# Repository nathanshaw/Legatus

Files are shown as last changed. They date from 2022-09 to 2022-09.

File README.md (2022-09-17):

# Legatus Hardware

This repo contains the PCB layout and schematic files for the Legatus genus.
Legatus is one of three genera developed for the Acropolis family of soundscape augmentation artefacts. Legatus specialises in loudspeaker-based cochlear soundscape augmentation.

The files were created within EAGLE CAD

The Legatus genus firmware is contained in this repo: https://github.com/nathanshaw/unified_hss_firmware

More information about this project can be found here: https://nathanvillicanashaw.com/archive
The Explorator genus can be found here: https://github.com/nathanshaw/explorator
The Speculator genus can be found here: https://github.com/nathanshaw/speculator

The following PCB design is included in this repo:
----------------------------------------------------

### Legatus major
    86mm diameter
    1x Teensy 3.2 Microcontroller
    1x power switch
    6x firmware control switches
    2x firmware control potentiometers
    10x WS2813 NeoPixel LEDs
    2x VEML 6030 Ambient Light Sensors
    1x 5v voltage regulator (D24V50F5): https://www.pololu.com/product/2851
    1x SHTC3 Temperature and Humidity Sensor
    2x onboard 18500 LiPo Batteries
    1x button controller IC
    1x audio amplifier breakout PCB
    1x SGTL5000 Breakout PCB
    2x TDK ICS-43434 MEMs microphone

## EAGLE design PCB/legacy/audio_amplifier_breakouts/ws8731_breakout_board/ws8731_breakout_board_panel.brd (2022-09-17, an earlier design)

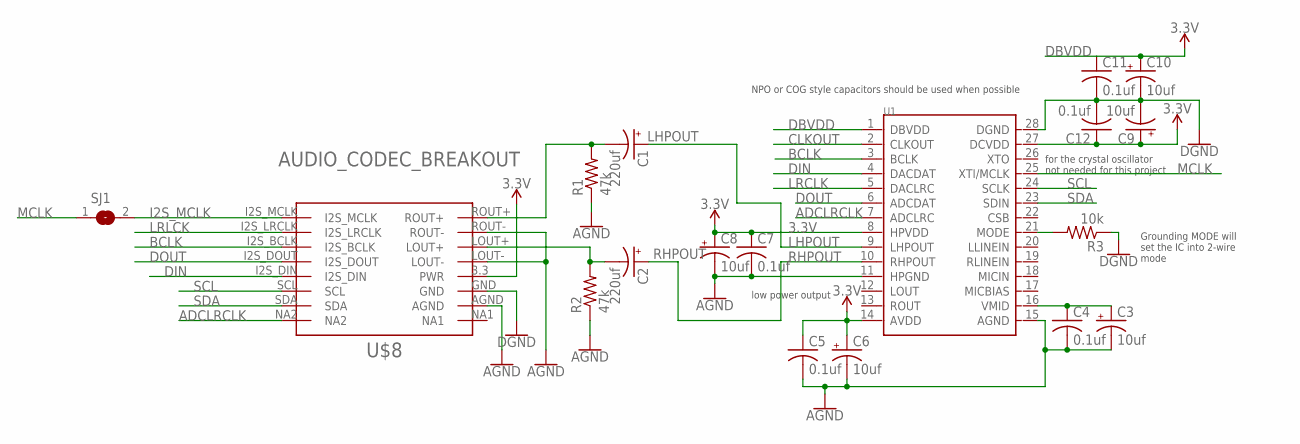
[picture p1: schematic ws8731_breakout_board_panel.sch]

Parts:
C1, C2: 220uf; PANASONIC_D
C3, C6, C8, C9, C10: 10uf; 153CLV-0505
C4, C5, C7, C11, C12: 0.1uf; C0805K
R1, R2: 47k; R0805
R3: 10k; R0805
SJ1: SJ
U1: CODECODER-WM8731SEDS/V(SSOP28); SSOP28-0.65-10.2X5.2MM
U$8: AUDIO_CODEC_BREAKOUT; HSS_CODEC_BREAKOUT

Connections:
3.3V: C5.1, C6.+, C7.1, C8.+, C9.+, C12.1, U1.8 (HPVDD), U1.14 (AVDD), U1.27 (DCVDD), U$8.3.3 (PWR)
ADCLRCLK: U1.7 (ADCLRC), U$8.NA2
AGND: C3.-, C4.2, C5.2, C6.-, C7.2, C8.-, R1.1, R2.1, U1.11 (HPGND), U1.15 (AGND), U$8.AGND, U$8.LOUT-, U$8.ROUT-
BCLK: U1.3 (BCLK), U$8.I2S_BCLK
CLKOUT: U1.2 (CLKOUT)
DBVDD: C10.+, C11.1, U1.1 (DBVDD)
DGND: C9.-, C10.-, C11.2, C12.2, R3.1, U1.28 (DGND)
DIN: U1.4 (DACDAT), U$8.I2S_DIN
DOUT: U1.6 (ADCDAT), U$8.I2S_DOUT
GND: U$8.GND
I2S_MCLK: SJ1.2, U$8.I2S_MCLK
LHPOUT: C1.+, U1.9 (LHPOUT)
LRCLK: U1.5 (DACLRC)
LRLCK: U$8.I2S_LRCLK
MCLK: SJ1.1, U1.25 (XTI/MCLK)
MODE: R3.2, U1.21 (MODE)
unnamed: C1.-, R1.2, U$8.ROUT+
unnamed: C2.-, R2.2, U$8.LOUT+
unnamed: C3.+, C4.1, U1.16 (VMID)
RHPOUT: C2.+, U1.10 (RHPOUT)
SCL: U1.24 (SCLK), U$8.SCL
SDA: U1.23 (SDIN), U$8.SDA

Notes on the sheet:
low power output
NPO or COG style capacitors should be used when possible
Grounding MODE will set the IC into 2-wire mode
for the crystal oscillator not needed for this project

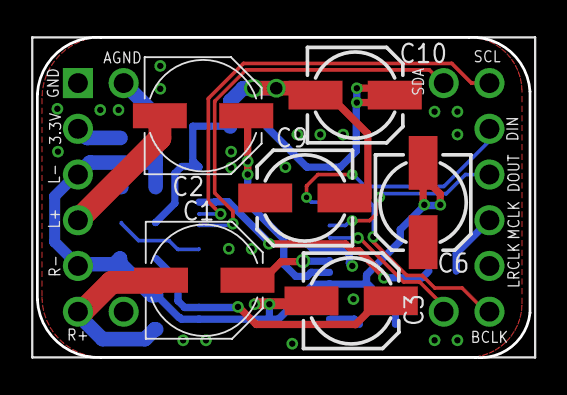
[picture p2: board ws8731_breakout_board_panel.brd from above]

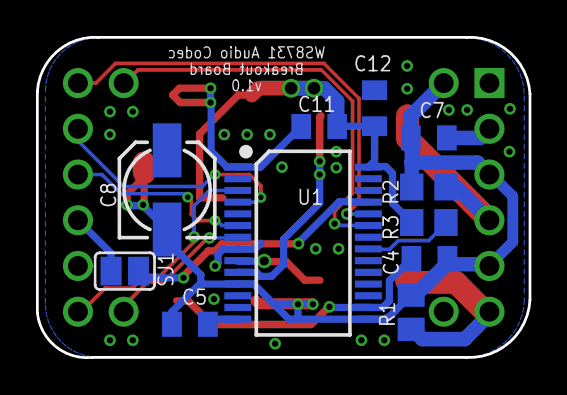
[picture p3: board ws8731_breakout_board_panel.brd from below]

Board: 2 copper layers, 27.4 x 17.8 mm, 18 parts (11 on the bottom side), 18 nets.

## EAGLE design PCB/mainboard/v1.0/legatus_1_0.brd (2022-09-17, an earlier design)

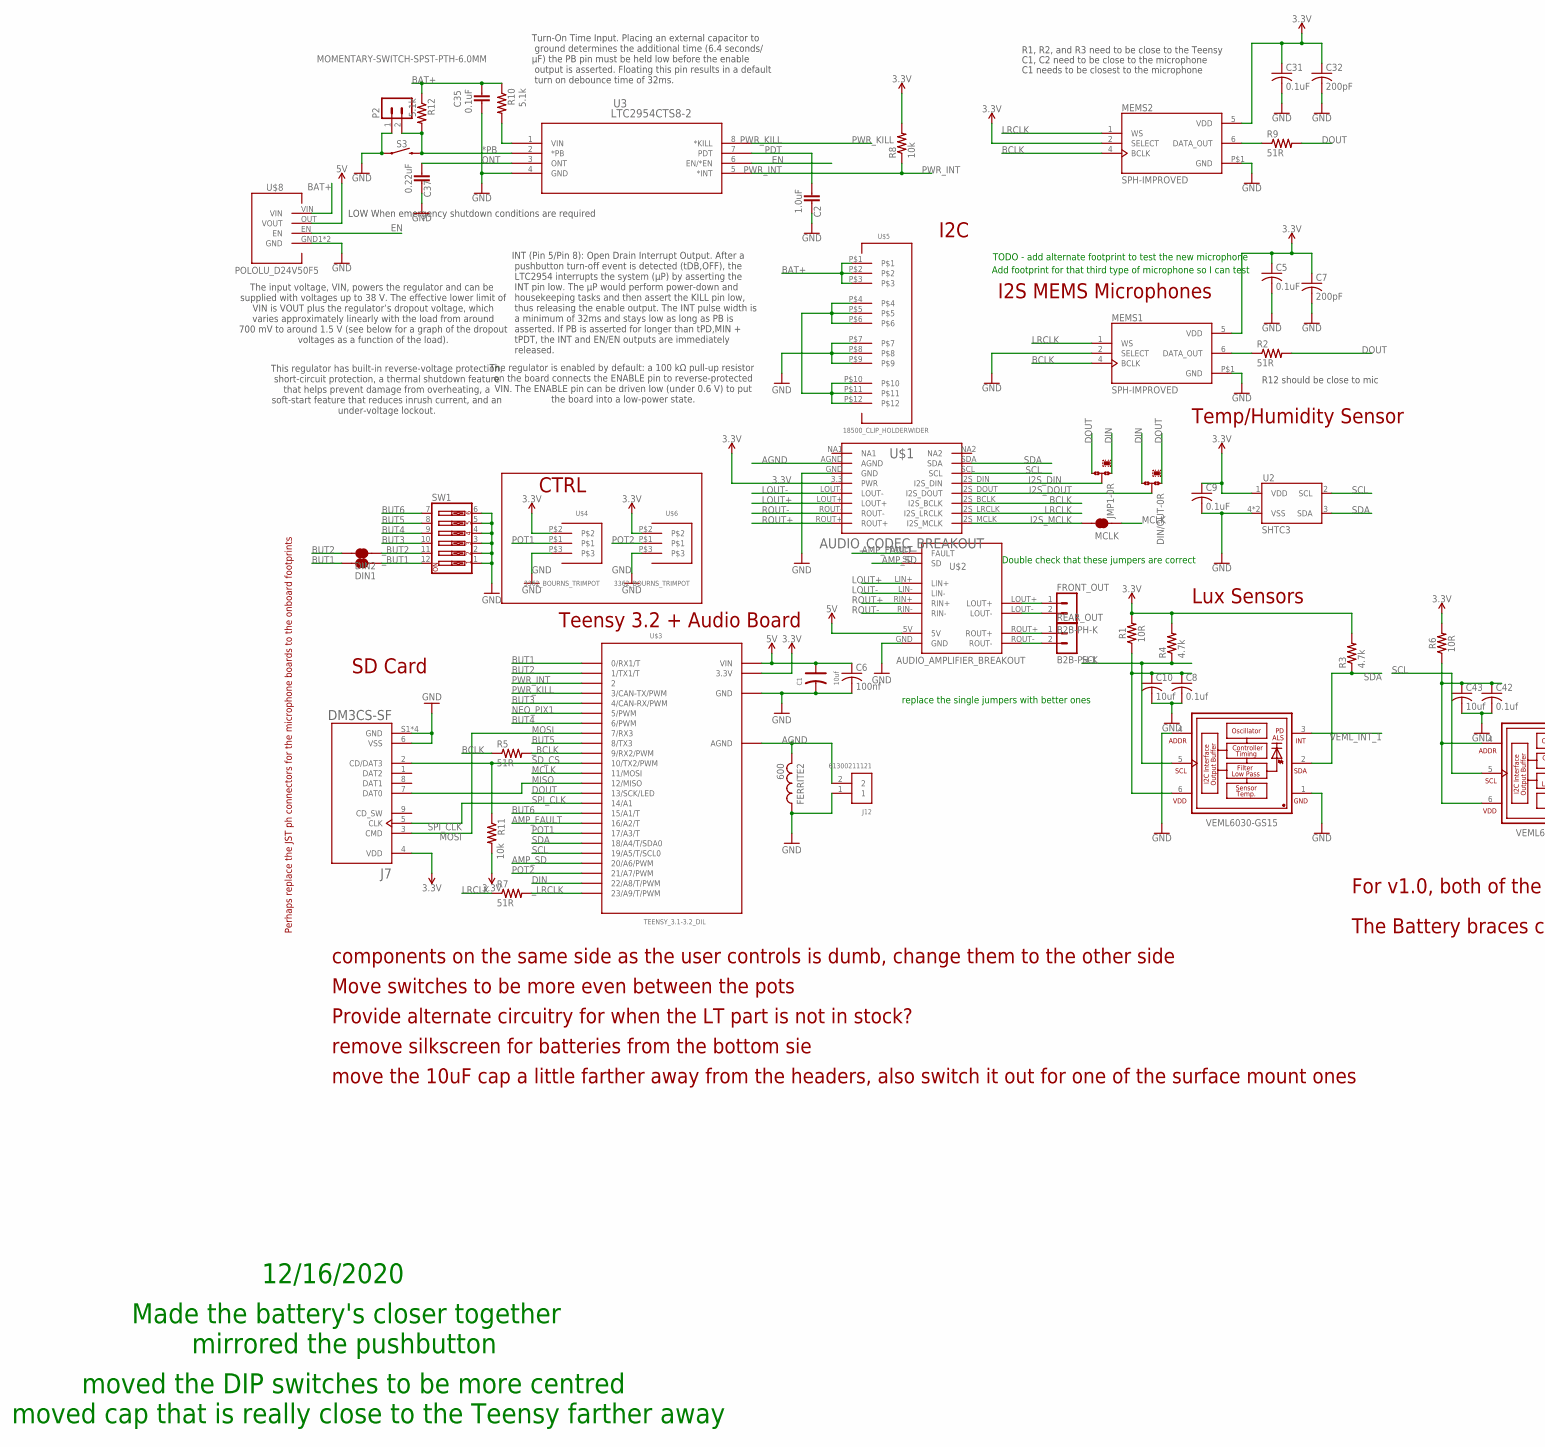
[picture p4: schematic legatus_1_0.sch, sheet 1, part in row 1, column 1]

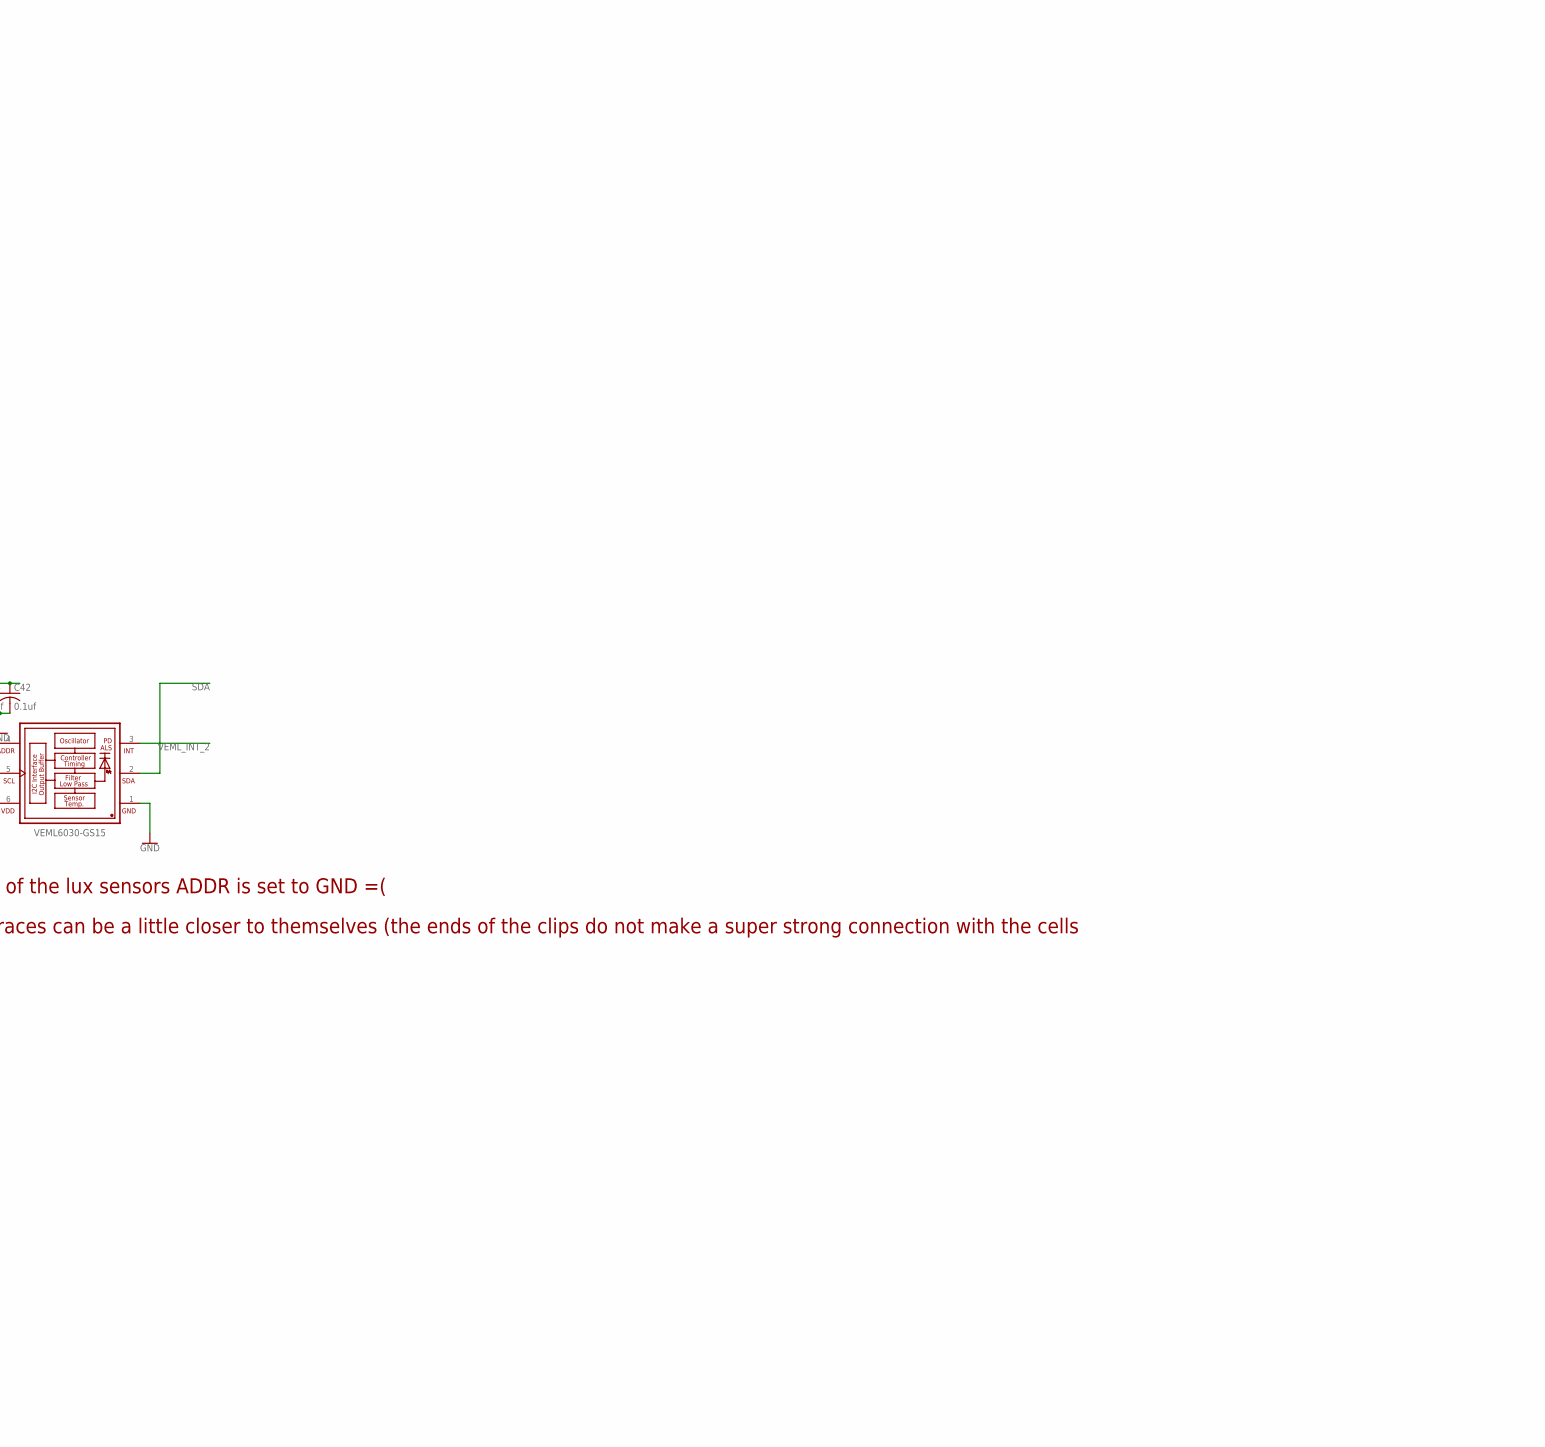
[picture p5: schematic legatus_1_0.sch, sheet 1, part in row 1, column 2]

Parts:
C1: 10uf; PC-D5.3MM
C2: 1.0uF; CAPC2012X110
C5, C9, C31: 0.1uF; C0805
C6: 100nf; C2012
C7, C32: 200pF; C0805
C8, C42: 0.1uf; C0805
C10, C43: 10uf; C0805
C35: 0.1uF; CAPC2012X110
C37: 0.22uF; CAPC2012X110
DIN1, DIN2: JUMPER-SMT_2_NC_TRACE_SILK; SMT-JUMPER_2_NC_TRACE_SILK
DIN/OUT: 0R-JUMPB; B0R-JMP
FERRITE2: 600; RESC0805_N
FRONT_OUT: B2B-PH-K
J7: DM3CS-SF; HRS_DM3CS-SF
J12: 61300211121
JMP1: 0R-JUMPB; B0R-JMP
MCLK: JUMPER-SMT_2_NC_TRACE_SILK; SMT-JUMPER_2_NC_TRACE_SILK
MEMS1, MEMS2: SPH-IMPROVED; MIC_SPH0645LM4H-B_LARGER_RING
P2: B2B-PH-K
R1, R6: 10R; R0805
R2, R5, R7, R9: 51R; M0805
R3, R4: 4.7k; M0805
R8: 10k; R0805
R10, R12: 5.1k; R0805
R11: 10k; M0805
REAR_OUT: B2B-PH-K
S3: MOMENTARY-SWITCH-SPST-PTH-6.0MM; TACTILE_SWITCH_PTH_6.0MM
SW1: SW_DIP-6; EDG-06
U2: SHTC3
U3: LTC2954CTS8-2; TSOT-23_TS8
U$1: AUDIO_CODEC_BREAKOUT; HSS_CODEC_BREAKOUT
U$2: AUDIO_AMPLIFIER_BREAKOUT
U$3: TEENSY_3.1-3.2_DIL; TEENSY_3.0-3.2&LC_DIL
U$4, U$6: 3362_BOURNS_TRIMPOT
U$5: 18500_CLIP_HOLDERWIDER; 3PINBATTERY_CLIP_WIDER
U$8: POLOLU_D24V50F5
VMEL1, VMEL2: VEML6030-GS15; VISHAY_VEML6030_2X2X0.87

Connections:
3.3V: C5.1, C7.1, C9.1, C31.1, C32.1, J7.4 (VDD), MEMS1.5 (VDD), MEMS2.2 (SELECT), MEMS2.5 (VDD), R1.2, R3.2, R4.2, R6.2, R8.2, R11.2, U2.1 (VDD), U$1.3.3 (PWR), U$3.3.3V, U$4.P$2, U$6.P$2
5V: C1.+, C6.1, U$2.5V, U$3.VIN, U$8.OUT (VOUT); also elsewhere on the board
*PB: P2.2, R12.2, S3.3 (2), U3.2 (*PB)
AGND: FERRITE2.2, J12.2, U$1.AGND, U$3.AGND
AMP_FAULT: U$2.FAULT, U$3.16/A2 (16/A2/T)
AMP_SD: U$2.SD, U$3.20/A6 (20/A6/PWM)
BAT+: C35.1, R10.1, R12.1, U$5.P$1, U$5.P$2, U$5.P$3, U$8.VIN
BCLK: MEMS1.4 (BCLK), MEMS2.4 (BCLK), R5.1, U$1.I2S_BCLK
BUT1: DIN1.1, U$3.0 (0/RX1/T)
BUT2: DIN2.1, U$3.1 (1/TX1/T)
BUT3: SW1.10, U$3.4 (4/CAN-RX/PWM)
BUT4: SW1.9, U$3.6 (6/PWM)
BUT5: SW1.8, U$3.8 (8/TX3)
BUT6: SW1.7, U$3.15/A1 (15/A1/T)
DIN: DIN/OUT.3, JMP1.1, U$3.22/A8 (22/A8/T/PWM)
DOUT: DIN/OUT.1, JMP1.3, R2.2, R9.2, U$3.13 (13/SCK/LED)
EN: U3.6 (EN/*EN), U$8.EN
GND: C1.-, C2.2, C5.2, C6.2, C7.2, C8.2, C9.2, C10.2, C31.2, C32.2, C35.2, C37.2, C42.2, C43.2, FERRITE2.1, J7.6 (VSS), J7.S1 (GND), J7.S2 (GND), J7.S3 (GND), J7.S5 (GND), J12.1, MEMS1.2 (SELECT), MEMS1.P$1 (GND), MEMS2.P$1 (GND), P2.1, S3.1, SW1.1, SW1.2, SW1.3, SW1.4, SW1.5, SW1.6, U2.4 (VSS), U2.5 (VSS), U3.4 (GND), U$1.GND, U$2.GND, U$3.GND, U$4.P$3, U$5.P$7, U$5.P$8, U$5.P$9, U$6.P$3, U$8.GND1 (GND), U$8.GND2 (GND), VMEL1.1 (GND), VMEL1.4 (ADDR), VMEL2.1 (GND); also elsewhere on the board
I2S_DIN: JMP1.2, U$1.I2S_DIN
I2S_DOUT: DIN/OUT.2, U$1.I2S_DOUT
I2S_MCLK: MCLK.1, U$1.I2S_MCLK
LOUT+: U$1.LOUT+, U$2.LIN+
LOUT-: U$1.LOUT-, U$2.LIN-
LRCLK: MEMS1.1 (WS), MEMS2.1 (WS), R7.1, U$1.I2S_LRCLK
MCLK: MCLK.2, U$3.11 (11/MOSI)
MISO: J7.7 (DAT0), U$3.12 (12/MISO)
MOSI: J7.3 (CMD), U$3.7 (7/RX3)
unnamed: MEMS1.6 (DATA_OUT), R2.1
unnamed: U$5.P$4, U$5.P$5, U$5.P$6, U$5.P$10, U$5.P$11, U$5.P$12
unnamed: C42.1, C43.1, R6.1, VMEL2.4 (ADDR), VMEL2.6 (VDD)
unnamed: C8.1, C10.1, R1.1, VMEL1.6 (VDD)
unnamed: R10.2, U3.1 (VIN)
unnamed: MEMS2.6 (DATA_OUT), R9.1
unnamed: REAR_OUT.2, U$2.ROUT-
unnamed: REAR_OUT.1, U$2.ROUT+
unnamed: FRONT_OUT.2, U$2.LOUT-
unnamed: FRONT_OUT.1, U$2.LOUT+
NEO_PIX1: U$3.5 (5/PWM); also elsewhere on the board
ONT: C37.1, U3.3 (ONT)
PDT: C2.1, U3.7 (PDT)
POT1: U$3.17/A3 (17/A3/T), U$4.P$1
POT2: U$3.21/A7 (21/A7/PWM), U$6.P$1
PWR_INT: R8.1, U3.5 (*INT), U$3.2
PWR_KILL: U3.8 (*KILL), U$3.3 (3/CAN-TX/PWM)
ROUT+: U$1.ROUT+, U$2.RIN+
ROUT-: U$1.ROUT-, U$2.RIN-
SCL: R4.1, U2.2 (SCL), U$1.SCL, U$3.19/A5 (19/A5/T/SCL0), VMEL1.5 (SCL), VMEL2.5 (SCL)
SDA: R3.1, U2.3 (SDA), U$1.SDA, U$3.18/A4 (18/A4/T/SDA0), VMEL1.2 (SDA), VMEL2.2 (SDA)
SD_CS: J7.2 (CD/DAT3), R11.1, U$3.10 (10/TX2/PWM)
SPI_CLK: J7.5 (CLK), U$3.14/A0 (14/A1)
VEML_INT_1: VMEL1.3 (INT)
VEML_INT_2: VMEL2.3 (INT)
_BCLK: R5.2, U$3.9 (9/RX2/PWM)
_BUT1: DIN1.2, SW1.12
_BUT2: DIN2.2, SW1.11
_LRCLK: R7.2, U$3.23/A9 (23/A9/T/PWM)

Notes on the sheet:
I2C
Teensy 3.2 + Audio Board
CTRL
Perhaps replace the JST ph connectors for the microphone boards to the onboard footprints
I2S MEMS Microphones
R12 should be close to mic
Temp/Humidity Sensor
10R
Lux Sensors
SD Card
Add footprint for that third type of microphone so I can test
R1, R2, and R3 need to be close to the Teensy
C1, C2 need to be close to the microphone
C1 needs to be closest to the microphone
This regulator has built-in reverse-voltage protection, short-circuit protection, a thermal shutdown feature that helps prevent damage from overheating, a soft-start feature that reduces inrush current, and an under-voltage lockout.
The input voltage, VIN, powers the regulator and can be supplied with voltages up to 38 V. The effective lower limit of VIN is VOUT plus the regulator’s dropout voltage, which varies approximately linearly with the load from around 700 mV to around 1.5 V (see below for a graph of the dropout voltag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
The regulator is enabled by default: a 100 kΩ pull-up resistor on the board connects the ENABLE pin to reverse-protected VIN. The ENABLE pin can be driven low (under 0.6 V) to put the board into a low-power state.
LOW When emergency shutdown conditions are required
Turn-On Time Input. Placing an external capacitor to ground determines the additional time (6.4 seconds/ μF) the PB pin must be held low before the enable output is asserted. Floating this pin results in a default turn on debounce time of 32ms.
INT (Pin 5/Pin 8): Open Drain Interrupt Output. After a pushbutton turn-off event is detected (tDB,OFF), the LTC2954 interrupts the system (μP) by asserting the INT pin low. The μP would perform power-down and housekeeping tasks and then assert the KILL pin low, thus releasing the enable output. Th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
TODO - add alternate footprint to test the new microphone
Double check that these jumpers are correct
replace the single jumpers with better ones
components on the same side as the user controls is dumb, change them to the other side
Move switches to be more even between the pots
remove silkscreen for batteries from the bottom sie
move the 10uF cap a little farther away from the headers, also switch it out for one of the surface mount ones
Provide alternate circuitry for when the LT part is not in stock?
For v1.0, both of the lux sensors ADDR is set to GND =(
The Battery braces can be a little closer to themselves (the ends of the clips do not make a super strong connection with the cells
Made the battery's closer together
12/16/2020
mirrored the pushbutton
moved the DIP switches to be more centred
moved cap that is really close to the Teensy farther away

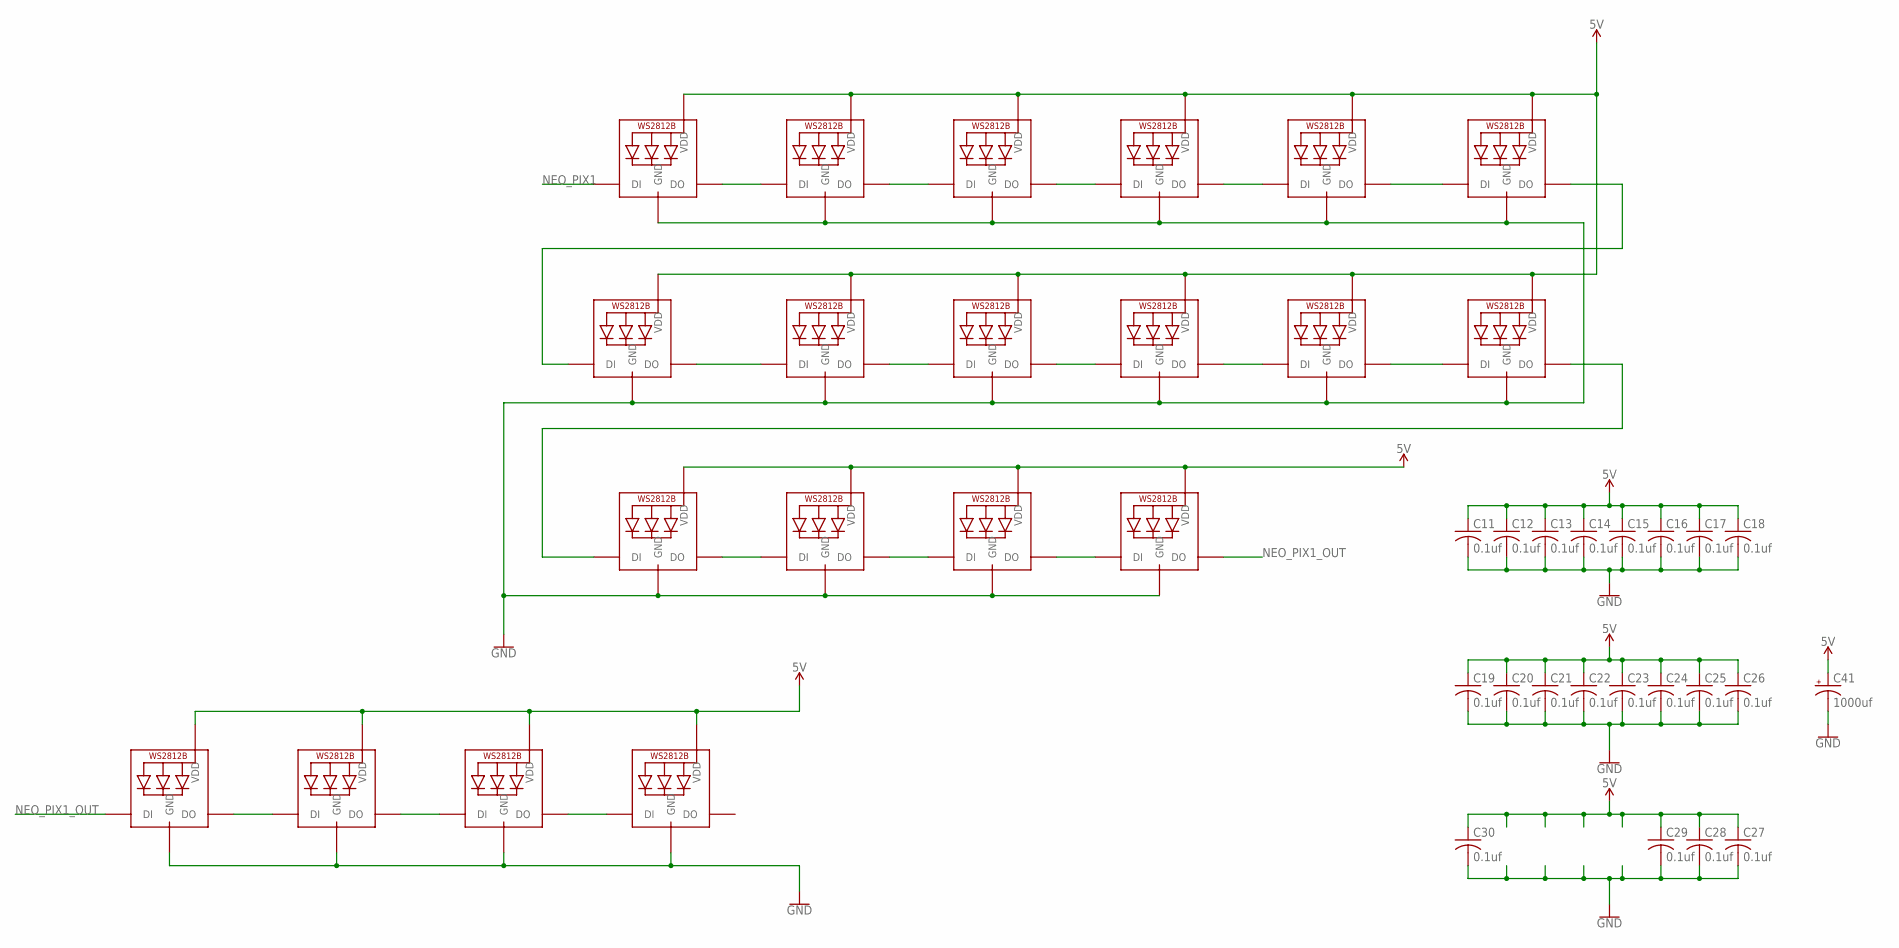
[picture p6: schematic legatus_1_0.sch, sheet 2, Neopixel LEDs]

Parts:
C11, C12, C13, C14, C15, C16, C17, C18, C19, C20, C21, C22, C23, C24, C25, C26, C27, C28, C29, C30: 0.1uf; C0805
C41: 1000uf; 153CLV-1010
LED1, LED2, LED3, LED4, LED5, LED6, LED7, LED8, LED9, LED10, LED11, LED12, LED13, LED14, LED15, LED16, LED17, LED18, LED19, LED20: WS2812B_5050N; WS2812B-NARROW

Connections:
5V: C11.1, C12.1, C13.1, C14.1, C15.1, C16.1, C17.1, C18.1, C19.1, C20.1, C21.1, C22.1, C23.1, C24.1, C25.1, C26.1, C27.1, C28.1, C29.1, C30.1, C41.+, LED1.1-VDD (VDD), LED2.1-VDD (VDD), LED3.1-VDD (VDD), LED4.1-VDD (VDD), LED5.1-VDD (VDD), LED6.1-VDD (VDD), LED7.1-VDD (VDD), LED8.1-VDD (VDD), LED9.1-VDD (VDD), LED10.1-VDD (VDD), LED11.1-VDD (VDD), LED12.1-VDD (VDD), LED13.1-VDD (VDD), LED14.1-VDD (VDD), LED15.1-VDD (VDD), LED16.1-VDD (VDD), LED17.1-VDD (VDD), LED18.1-VDD (VDD), LED19.1-VDD (VDD), LED20.1-VDD (VDD); also elsewhere on the board
GND: C11.2, C12.2, C13.2, C14.2, C15.2, C16.2, C17.2, C18.2, C19.2, C20.2, C21.2, C22.2, C23.2, C24.2, C25.2, C26.2, C27.2, C28.2, C29.2, C30.2, C41.-, LED1.3-GND (GND), LED2.3-GND (GND), LED3.3-GND (GND), LED4.3-GND (GND), LED5.3-GND (GND), LED6.3-GND (GND), LED7.3-GND (GND), LED8.3-GND (GND), LED9.3-GND (GND), LED10.3-GND (GND), LED11.3-GND (GND), LED12.3-GND (GND), LED13.3-GND (GND), LED14.3-GND (GND), LED15.3-GND (GND), LED16.3-GND (GND), LED17.3-GND (GND), LED18.3-GND (GND), LED19.3-GND (GND), LED20.3-GND (GND); also elsewhere on the board
unnamed: LED1.2-DOUT (DO), LED2.4-DIN (DI)
unnamed: LED2.2-DOUT (DO), LED3.4-DIN (DI)
unnamed: LED3.2-DOUT (DO), LED4.4-DIN (DI)
unnamed: LED4.2-DOUT (DO), LED5.4-DIN (DI)
unnamed: LED5.2-DOUT (DO), LED6.4-DIN (DI)
unnamed: LED7.2-DOUT (DO), LED8.4-DIN (DI)
unnamed: LED8.2-DOUT (DO), LED9.4-DIN (DI)
unnamed: LED9.2-DOUT (DO), LED10.4-DIN (DI)
unnamed: LED10.2-DOUT (DO), LED11.4-DIN (DI)
unnamed: LED11.2-DOUT (DO), LED12.4-DIN (DI)
unnamed: LED13.2-DOUT (DO), LED14.4-DIN (DI)
unnamed: LED14.2-DOUT (DO), LED15.4-DIN (DI)
unnamed: LED15.2-DOUT (DO), LED16.4-DIN (DI)
unnamed: LED12.2-DOUT (DO), LED13.4-DIN (DI)
unnamed: LED6.2-DOUT (DO), LED7.4-DIN (DI)
unnamed: LED18.2-DOUT (DO), LED19.4-DIN (DI)
unnamed: LED19.2-DOUT (DO), LED20.4-DIN (DI)
unnamed: LED17.2-DOUT (DO), LED18.4-DIN (DI)
NEO_PIX1: LED1.4-DIN (DI); also elsewhere on the board
NEO_PIX1_OUT: LED16.2-DOUT (DO), LED17.4-DIN (DI)

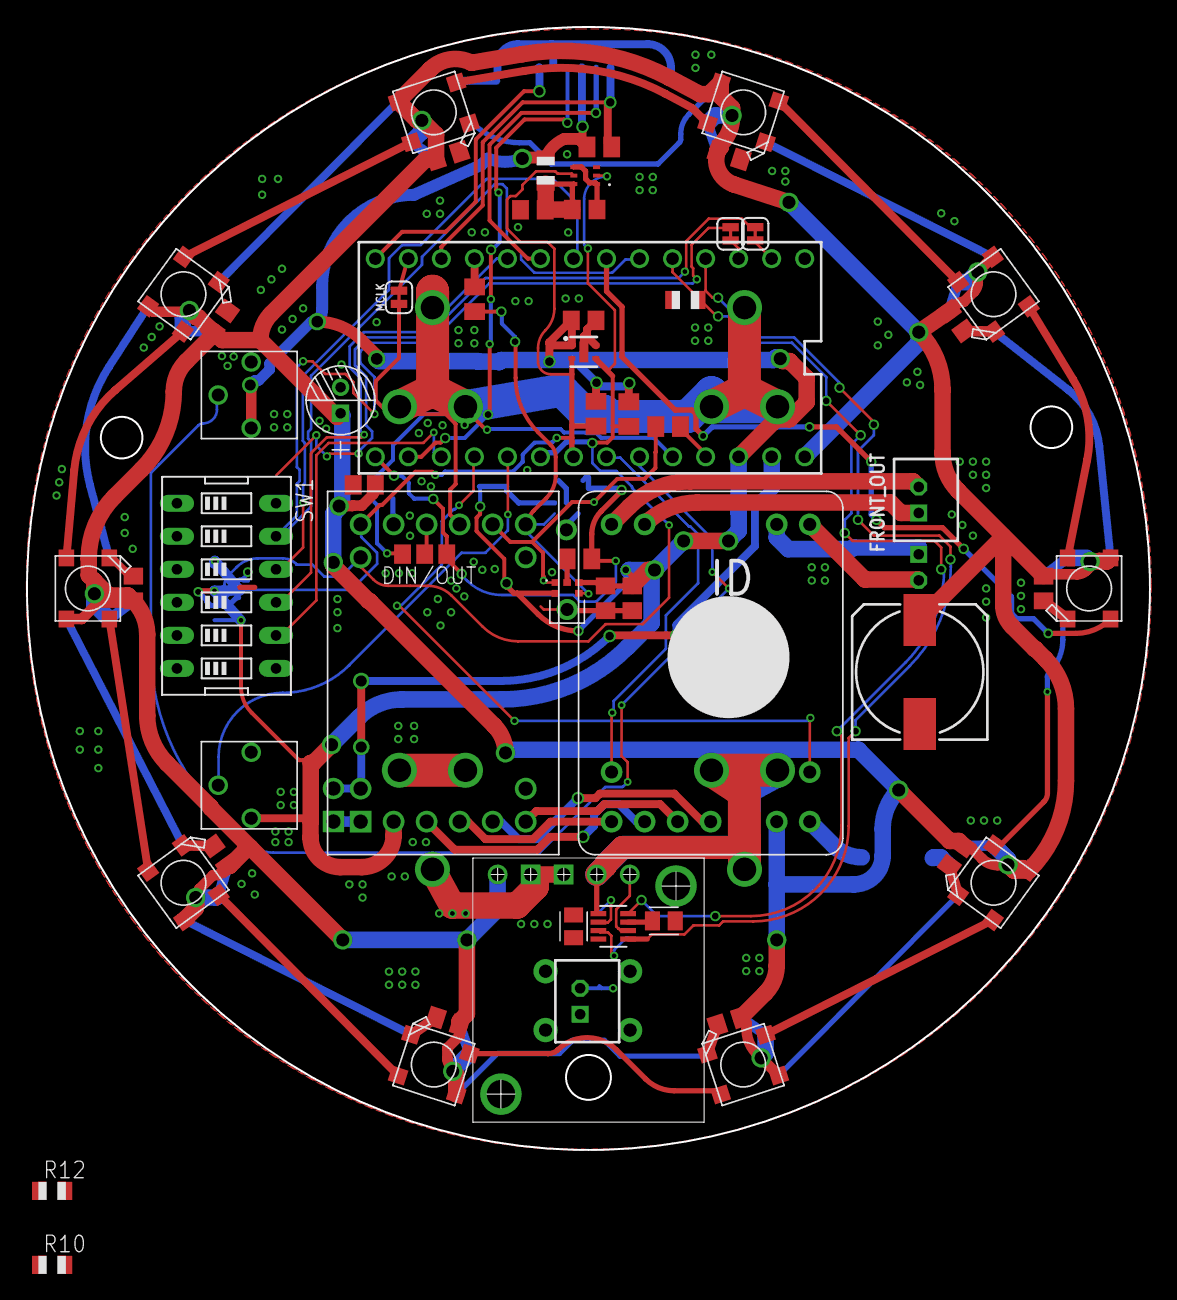
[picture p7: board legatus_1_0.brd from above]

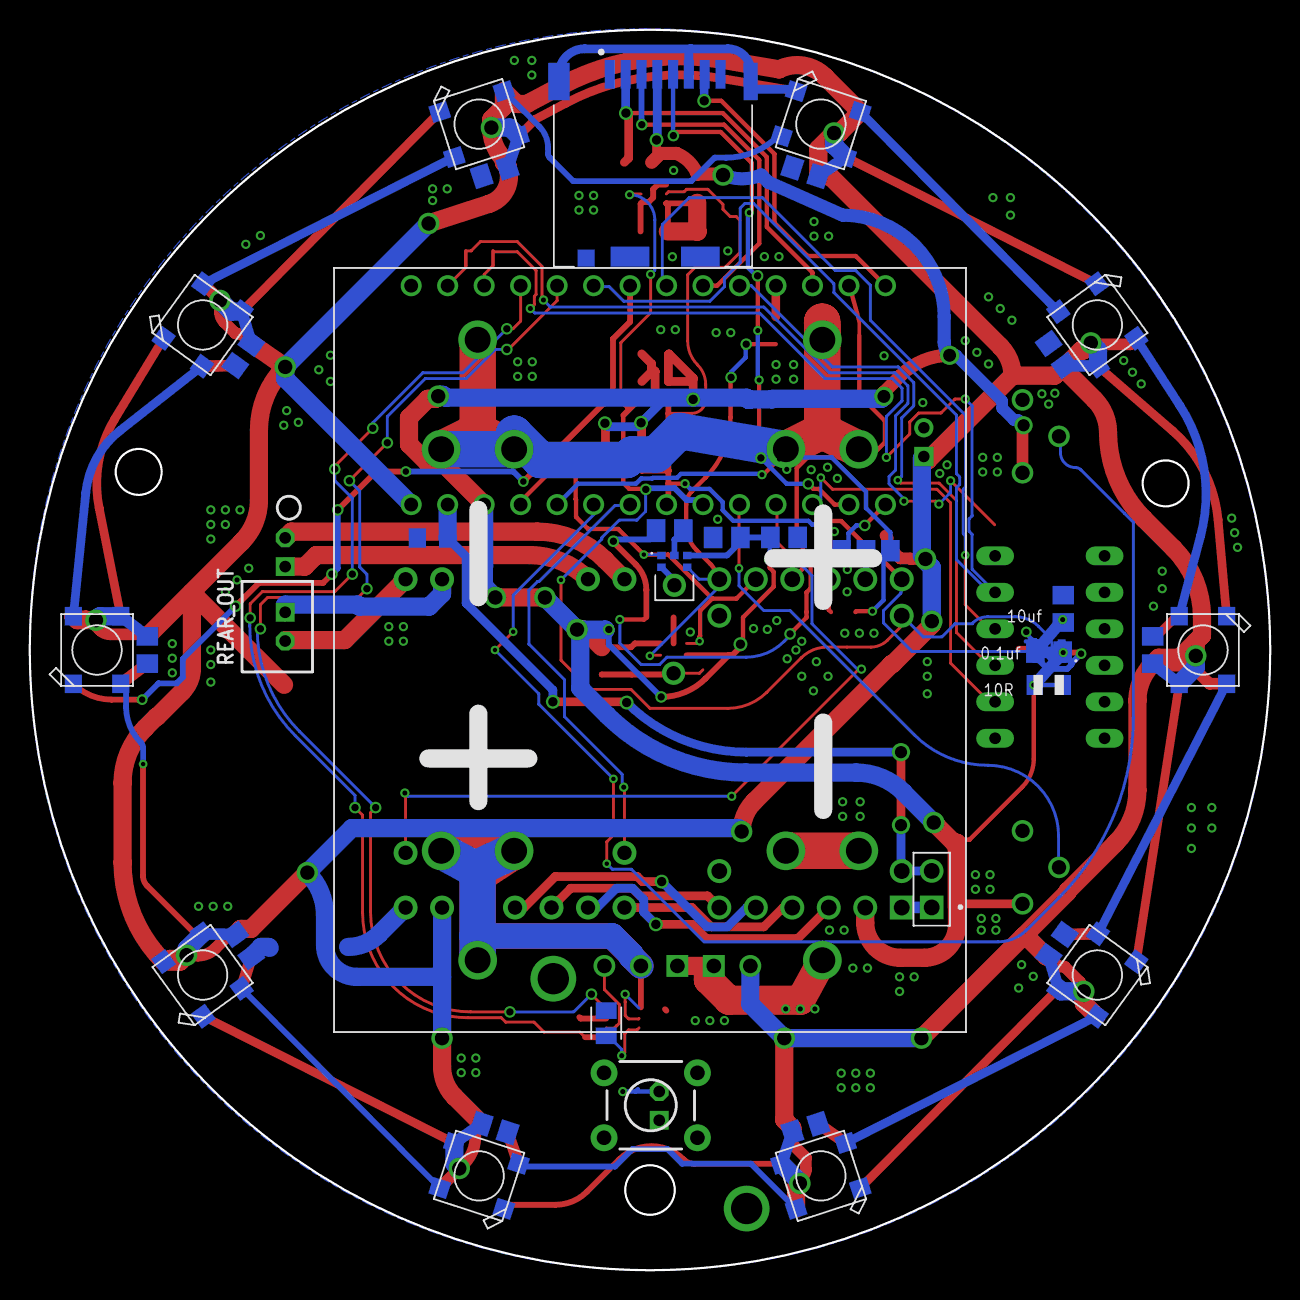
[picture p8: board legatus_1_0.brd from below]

Board: 2 copper layers, 86.4 x 86.4 mm, 93 parts (36 on the bottom side), 73 nets.

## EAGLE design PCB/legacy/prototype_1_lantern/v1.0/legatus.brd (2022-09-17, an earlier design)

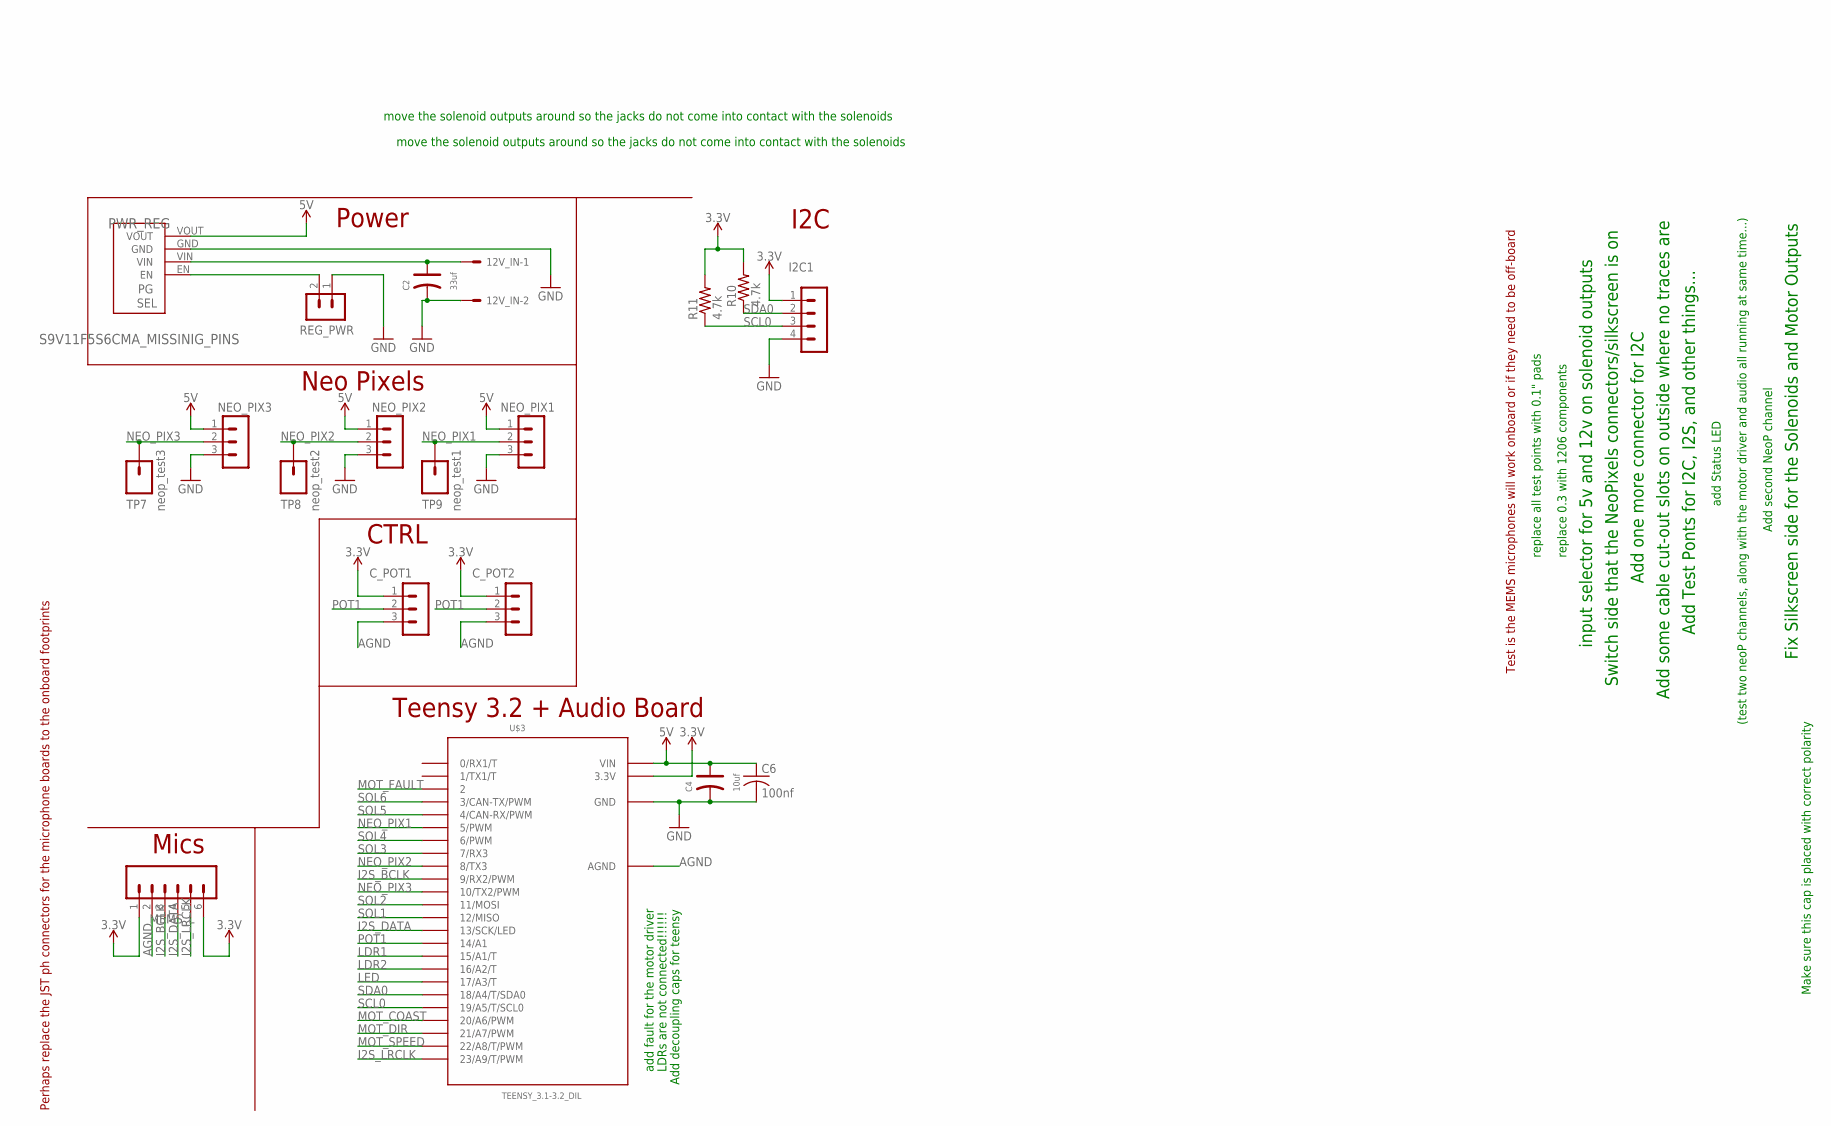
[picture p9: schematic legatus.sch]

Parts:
12V_IN: 5566-2
C2: 33uf; PC-D5.3MM
C4: 10uf; PC-D5.3MM
C6: 100nf; C2012
C_POT1, C_POT2: B3B-PH-K
I2C1: B4B-PH-K
MEMS_L: CONN_06POLAR; MOLEX-1X6
NEO_PIX1, NEO_PIX2, NEO_PIX3: B3B-PH-K
PWR_REG: S9V11F5S6CMA_MISSINIG_PINS; S9V11F3S5CMA_MISSING_PINS
R10, R11: 4.7k; M1206
REG_PWR: B2B-PH-K
TP7: neop_test3; 1X01
TP8: neop_test2; 1X01
TP9: neop_test1; 1X01
U$3: TEENSY_3.1-3.2_DIL; TEENSY_3.0-3.2&LC_DIL

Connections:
3.3V: C_POT1.1, C_POT2.1, I2C1.1, MEMS_L.1, MEMS_L.6, R10.2, R11.2, U$3.3.3V
5V: C4.+, C6.1, NEO_PIX1.1, NEO_PIX2.1, NEO_PIX3.1, PWR_REG.VOUT, U$3.VIN
12V: 12V_IN.1, C2.+, PWR_REG.VIN
AGND: C_POT1.3, C_POT2.3, MEMS_L.2, U$3.AGND
GND: 12V_IN.2, C2.-, C4.-, C6.2, I2C1.4, NEO_PIX1.3, NEO_PIX2.3, NEO_PIX3.3, PWR_REG.GND, REG_PWR.1, U$3.GND
I2S_BCLK: MEMS_L.3, U$3.9 (9/RX2/PWM)
I2S_DATA: MEMS_L.4, U$3.13 (13/SCK/LED)
I2S_LRCLK: MEMS_L.5, U$3.23/A9 (23/A9/T/PWM)
LDR1: U$3.15/A1 (15/A1/T)
LDR2: U$3.16/A2 (16/A2/T)
LED: U$3.17/A3 (17/A3/T)
MOT_COAST: U$3.20/A6 (20/A6/PWM)
MOT_DIR: U$3.21/A7 (21/A7/PWM)
MOT_FAULT: U$3.2
MOT_SPEED: U$3.22/A8 (22/A8/T/PWM)
unnamed: PWR_REG.EN, REG_PWR.2
NEO_PIX1: NEO_PIX1.2, TP9.1, U$3.5 (5/PWM)
NEO_PIX2: NEO_PIX2.2, TP8.1, U$3.8 (8/TX3)
NEO_PIX3: NEO_PIX3.2, TP7.1, U$3.10 (10/TX2/PWM)
POT1: C_POT1.2, C_POT2.2, U$3.14/A0 (14/A1)
SCL0: I2C1.3, R11.1, U$3.19/A5 (19/A5/T/SCL0)
SDA0: I2C1.2, R10.1, U$3.18/A4 (18/A4/T/SDA0)
SOL1: U$3.12 (12/MISO)
SOL2: U$3.11 (11/MOSI)
SOL3: U$3.7 (7/RX3)
SOL4: U$3.6 (6/PWM)
SOL5: U$3.4 (4/CAN-RX/PWM)
SOL6: U$3.3 (3/CAN-TX/PWM)

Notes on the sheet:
Neo Pixels
I2C
Teensy 3.2 + Audio Board
Mics
Power
Make sure this cap is placed with correct polarity
CTRL
add fault for the motor driver
LDRs are not connected!!!!!!
Fix Silkscreen side for the Solenoids and Motor Outputs
Add Test Ponts for I2C, I2S, and other things...
Add some cable cut-out slots on outside where no traces are
Add one more connector for I2C
Switch side that the NeoPixels connectors/silkscreen is on
input selector for 5v and 12v on solenoid outputs
Add second NeoP channel
(test two neoP channels, along with the motor driver and audio all running at same time...)
add Status LED
replace 0.3 with 1206 components
replace all test points with 0.1" pads
Add decoupling caps for teensy
Test is the MEMS microphones will work onboard or if they need to be off-board
Perhaps replace the JST ph connectors for the microphone boards to the onboard footprints
move the solenoid outputs around so the jacks do not come into contact with the solenoids

Board: 2 copper layers, 19 parts (0 on the bottom side), 15 nets, no tracks yet.

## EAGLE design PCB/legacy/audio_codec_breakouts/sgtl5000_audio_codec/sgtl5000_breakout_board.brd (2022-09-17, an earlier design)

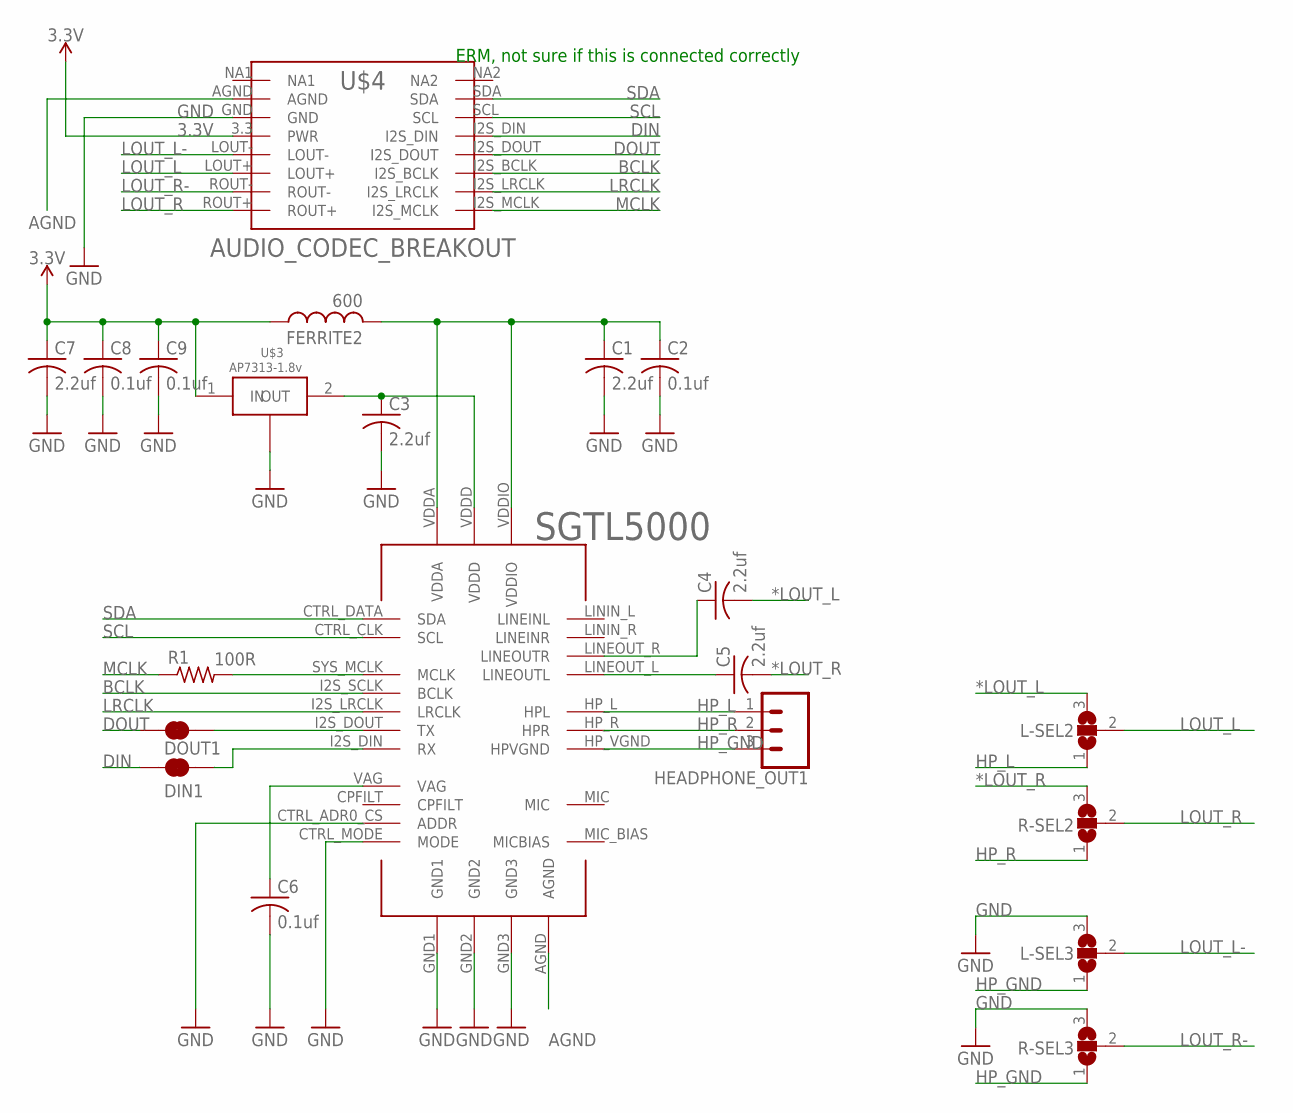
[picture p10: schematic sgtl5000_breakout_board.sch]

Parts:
C1, C3, C4, C5, C7: 2.2uf; C0805
C2, C6, C8, C9: 0.1uf; C0805
DIN1: JUMPER-SMT_2_NC_TRACE_SILK; SMT-JUMPER_2_NC_TRACE_SILK
DOUT1: JUMPER-SMT_2_NC_TRACE_SILK; SMT-JUMPER_2_NC_TRACE_SILK
FERRITE2: 600; RESC0805_N
HEADPHONE_OUT1: CONN_03; 1X03
L-SEL2, L-SEL3: SJ2W; SJ_2
R1: 100R; M0805
R-SEL2, R-SEL3: SJ2W; SJ_2
U$2: SGTL5000; QFN-32-5X5MM
U$3: AP7313-1.8v; SOT-23
U$4: AUDIO_CODEC_BREAKOUT; HSS_CODEC_BREAKOUT

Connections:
3.3V: C7.1, C8.1, C9.1, FERRITE2.1, U$3.1 (IN), U$4.3.3 (PWR)
*LOUT_L: C4.2, L-SEL2.3
*LOUT_R: C5.2, R-SEL2.3
AGND: U$2.AGND, U$4.AGND
BCLK: U$2.I2S_SCLK (BCLK), U$4.I2S_BCLK
DIN: DIN1.1, U$4.I2S_DIN
DOUT: DOUT1.1, U$4.I2S_DOUT
EDITROUTE1: C1.1, C2.1, FERRITE2.2, U$2.VDDA, U$2.VDDIO
GND: C1.2, C2.2, C3.2, C6.2, C7.2, C8.2, C9.2, L-SEL3.3, R-SEL3.3, U$2.CTRL_ADR0_CS (ADDR), U$2.CTRL_MODE (MODE), U$2.GND1, U$2.GND2, U$2.GND3, U$3.3 (GND), U$4.GND
HP_GND: HEADPHONE_OUT1.3, L-SEL3.1, R-SEL3.1, U$2.HP_VGND (HPVGND)
HP_L: HEADPHONE_OUT1.1, L-SEL2.1, U$2.HP_L (HPL)
HP_R: HEADPHONE_OUT1.2, R-SEL2.1, U$2.HP_R (HPR)
LOUT_L: L-SEL2.2, U$4.LOUT+
LOUT_L-: L-SEL3.2, U$4.LOUT-
LOUT_R: R-SEL2.2, U$4.ROUT+
LOUT_R-: R-SEL3.2, U$4.ROUT-
LRCLK: U$2.I2S_LRCLK (LRCLK), U$4.I2S_LRCLK
MCLK: R1.1, U$4.I2S_MCLK
unnamed: C4.1, U$2.LINEOUT_R (LINEOUTR)
unnamed: C5.1, U$2.LINEOUT_L (LINEOUTL)
unnamed: C6.1, U$2.VAG
unnamed: DIN1.2, U$2.I2S_DIN (RX)
unnamed: DOUT1.2, U$2.I2S_DOUT (TX)
unnamed: R1.2, U$2.SYS_MCLK (MCLK)
unnamed: C3.1, U$2.VDDD, U$3.2 (OUT)
SCL: U$2.CTRL_CLK (SCL), U$4.SCL
SDA: U$2.CTRL_DATA (SDA), U$4.SDA

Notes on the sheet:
ERM, not sure if this is connected correctly

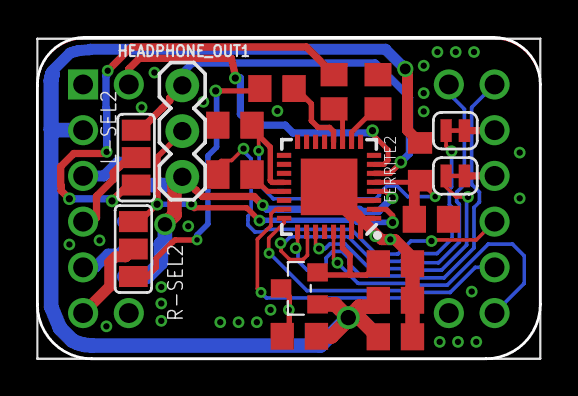
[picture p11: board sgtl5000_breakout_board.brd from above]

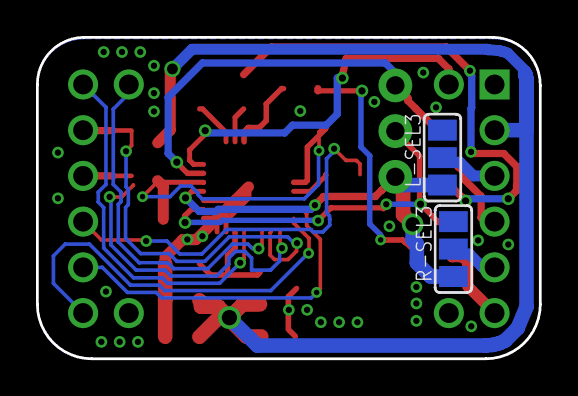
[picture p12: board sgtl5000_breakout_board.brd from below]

Board: 2 copper layers, 27.9 x 17.9 mm, 21 parts (2 on the bottom side), 27 nets.

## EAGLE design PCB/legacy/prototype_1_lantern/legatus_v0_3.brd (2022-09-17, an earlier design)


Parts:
BT1, BT2: BATTERY-18650; BATTERY_18650-HOLDER
C1: 10uf; PC-D5.3MM
C2: 33uf; PC-D5.3MM
C5, C9: 0.1uF; C0805
C6: 100nf; C2012
C7: 200pF; C0805
C8: 0.1uf; C0805
C10: 10uf; C0805
DIN1, DIN2: JUMPER-SMT_2_NC_TRACE_SILK; SMT-JUMPER_2_NC_TRACE_SILK
FERRITE2: 600; RESC0805_N
J7: DM3CS-SF; HRS_DM3CS-SF
MEMS1: SPH-IMPROVED; MIC_SPH0645LM4H-B_LARGER_RING
NEO_PIX2: B3B-PH-K
PWR_REG: S9V11F5S6CMA; S9V11F3S5CMA
R1: 10R; R0805
R2: 68R; M0805
R3, R4: 4.7k; M0805
R11: 10k; M0805
S1: DIP-08-PTH; DIPSWITCH-08
S2: SWITCH-SPDT-PTH-11.6X4.0MM-LOCK; SWITCH_SPDT_PTH_11.6X4.0MM_LOCK
U2: SHTC3
U$3: TEENSY_3.1-3.2_DIL; TEENSY_3.0-3.2&LC_DIL
U$4, U$6: 3362_BOURNS_TRIMPOT
VEML1: VEML7700-TT; VEML7700
VMEL1: VEML6030-GS15; VISHAY_VEML6030_2X2X0.87

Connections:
3.3V: C5.1, C7.1, C9.1, J7.4 (VDD), MEMS1.5 (VDD), R1.2, R3.2, R4.2, R11.2, U2.1 (VDD), U$3.3.3V, U$4.P$2; also elsewhere on the board
5V: C1.+, C6.1, NEO_PIX2.1, PWR_REG.VOUT, U$3.VIN, U$6.P$2; also elsewhere on the board
AGND: FERRITE2.2, U$3.AGND, U$4.P$3, U$6.P$3; also elsewhere on the board
BCLK: MEMS1.4 (BCLK), U$3.9 (9/RX2/PWM); also elsewhere on the board
BUT1: DIN1.1, U$3.0 (0/RX1/T)
BUT2: DIN2.1, U$3.1 (1/TX1/T)
BUT3: S1.14, U$3.4 (4/CAN-RX/PWM)
BUT4: S1.13, U$3.6 (6/PWM)
BUT5: S1.12, U$3.15/A1 (15/A1/T)
BUT6: S1.11, U$3.16/A2 (16/A2/T)
BUT7: S1.10, U$3.20/A6 (20/A6/PWM)
BUT8: S1.9, U$3.21/A7 (21/A7/PWM)
DIN: U$3.22/A8 (22/A8/T/PWM); also elsewhere on the board
DOUT: R2.2, U$3.13 (13/SCK/LED); also elsewhere on the board
GND: BT2.GND@1 (-), C1.-, C2.-, C5.2, C6.2, C7.2, C8.2, C9.2, C10.2, FERRITE2.1, J7.6 (VSS), J7.S1 (GND), J7.S2 (GND), J7.S3 (GND), J7.S5 (GND), MEMS1.2 (SELECT), MEMS1.P$1 (GND), NEO_PIX2.3, PWR_REG.GND, S1.1, S1.2, S1.3, S1.4, S1.5, S1.6, S1.7, S1.8, S2.1 (O), U2.4 (VSS), U2.5 (VSS), U$3.GND, VEML1.3 (GND), VMEL1.1 (GND), VMEL1.4 (ADDR); also elsewhere on the board
LRCLK: MEMS1.1 (WS), U$3.23/A9 (23/A9/T/PWM); also elsewhere on the board
MCLK: U$3.11 (11/MOSI); also elsewhere on the board
MISO: J7.7 (DAT0), U$3.12 (12/MISO)
MOSI: J7.3 (CMD), U$3.7 (7/RX3)
unnamed: MEMS1.6 (DATA_OUT), R2.1
unnamed: C8.1, C10.1, R1.1, VEML1.2 (VDD), VMEL1.6 (VDD)
unnamed: PWR_REG.EN, S2.2
unnamed: BT1.GND@1 (-), BT2.PWR@1 (+)
NEO_PIX1: U$3.5 (5/PWM); also elsewhere on the board
NEO_PIX2: NEO_PIX2.2, U$3.8 (8/TX3)
POT1: U$3.17/A3 (17/A3/T), U$4.P$1
SCL: R4.1, U2.2 (SCL), U$3.19/A5 (19/A5/T/SCL0), VEML1.1 (SCL), VMEL1.5 (SCL); also elsewhere on the board
SDA: R3.1, U2.3 (SDA), U$3.18/A4 (18/A4/T/SDA0), VEML1.4 (SDA), VMEL1.2 (SDA); also elsewhere on the board
SD_CS: J7.2 (CD/DAT3), R11.1, U$3.10 (10/TX2/PWM)
SPI_CLK: J7.5 (CLK), U$3.14/A0 (14/A1)
TPA_SHDN: U$3.3 (3/CAN-TX/PWM); also elsewhere on the board
VEML_INT: U$3.2, VMEL1.3 (INT)
VIN: BT1.PWR@1 (+), C2.+, PWR_REG.VIN
VOL: U$6.P$1; also elsewhere on the board
_BUT1: DIN1.2, S1.16
_BUT2: DIN2.2, S1.15

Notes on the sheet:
Neo Pixels
I2C
Teensy 3.2 + Audio Board
Power
CTRL
Add Test Ponts for I2C, I2S, and other things...
Add some cable cut-out slots on outside where no traces are
Perhaps replace the JST ph connectors for the microphone boards to the onboard footprints
I2S MEMS Microphones
R12 should be close to mic
Temp/Humidity Sensor
10R
Lux Sensors
SD Card


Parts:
C11, C12, C13, C14, C15, C16, C17, C18, C19, C20, C21, C22, C23, C24, C25, C26, C30, C31, C35, C36, C37, C38, C39, C40: 0.1uf; C0805
C41: 1000uf; 153CLV-1010
LED1, LED2, LED3, LED4, LED5, LED6, LED7, LED8, LED9, LED10, LED11, LED12, LED13, LED14, LED15, LED16, LED17, LED18, LED19, LED20, LED21, LED22, LED23, LED24: WS2812B_5050N; WS2812B-NARROW

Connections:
5V: C11.1, C12.1, C13.1, C14.1, C15.1, C16.1, C17.1, C18.1, C19.1, C20.1, C21.1, C22.1, C23.1, C24.1, C25.1, C26.1, C30.1, C31.1, C35.1, C36.1, C37.1, C38.1, C39.1, C40.1, C41.+, LED1.1-VDD (VDD), LED2.1-VDD (VDD), LED3.1-VDD (VDD), LED4.1-VDD (VDD), LED5.1-VDD (VDD), LED6.1-VDD (VDD), LED7.1-VDD (VDD), LED8.1-VDD (VDD), LED9.1-VDD (VDD), LED10.1-VDD (VDD), LED11.1-VDD (VDD), LED12.1-VDD (VDD), LED13.1-VDD (VDD), LED14.1-VDD (VDD), LED15.1-VDD (VDD), LED16.1-VDD (VDD), LED17.1-VDD (VDD), LED18.1-VDD (VDD), LED19.1-VDD (VDD), LED20.1-VDD (VDD), LED21.1-VDD (VDD), LED22.1-VDD (VDD), LED23.1-VDD (VDD), LED24.1-VDD (VDD); also elsewhere on the board
GND: C11.2, C12.2, C13.2, C14.2, C15.2, C16.2, C17.2, C18.2, C19.2, C20.2, C21.2, C22.2, C23.2, C24.2, C25.2, C26.2, C30.2, C31.2, C35.2, C36.2, C37.2, C38.2, C39.2, C40.2, C41.-, LED1.3-GND (GND), LED2.3-GND (GND), LED3.3-GND (GND), LED4.3-GND (GND), LED5.3-GND (GND), LED6.3-GND (GND), LED7.3-GND (GND), LED8.3-GND (GND), LED9.3-GND (GND), LED10.3-GND (GND), LED11.3-GND (GND), LED12.3-GND (GND), LED13.3-GND (GND), LED14.3-GND (GND), LED15.3-GND (GND), LED16.3-GND (GND), LED17.3-GND (GND), LED18.3-GND (GND), LED19.3-GND (GND), LED20.3-GND (GND), LED21.3-GND (GND), LED22.3-GND (GND), LED23.3-GND (GND), LED24.3-GND (GND); also elsewhere on the board
unnamed: LED1.2-DOUT (DO), LED2.4-DIN (DI)
unnamed: LED2.2-DOUT (DO), LED3.4-DIN (DI)
unnamed: LED3.2-DOUT (DO), LED4.4-DIN (DI)
unnamed: LED4.2-DOUT (DO), LED5.4-DIN (DI)
unnamed: LED5.2-DOUT (DO), LED6.4-DIN (DI)
unnamed: LED7.2-DOUT (DO), LED8.4-DIN (DI)
unnamed: LED8.2-DOUT (DO), LED9.4-DIN (DI)
unnamed: LED9.2-DOUT (DO), LED10.4-DIN (DI)
unnamed: LED10.2-DOUT (DO), LED11.4-DIN (DI)
unnamed: LED11.2-DOUT (DO), LED12.4-DIN (DI)
unnamed: LED13.2-DOUT (DO), LED14.4-DIN (DI)
unnamed: LED14.2-DOUT (DO), LED15.4-DIN (DI)
unnamed: LED15.2-DOUT (DO), LED16.4-DIN (DI)
unnamed: LED12.2-DOUT (DO), LED13.4-DIN (DI)
unnamed: LED6.2-DOUT (DO), LED7.4-DIN (DI)
unnamed: LED18.2-DOUT (DO), LED19.4-DIN (DI)
unnamed: LED19.2-DOUT (DO), LED20.4-DIN (DI)
unnamed: LED20.2-DOUT (DO), LED21.4-DIN (DI)
unnamed: LED21.2-DOUT (DO), LED22.4-DIN (DI)
unnamed: LED22.2-DOUT (DO), LED23.4-DIN (DI)
unnamed: LED23.2-DOUT (DO), LED24.4-DIN (DI)
unnamed: LED17.2-DOUT (DO), LED18.4-DIN (DI)
NEO_PIX1: LED1.4-DIN (DI); also elsewhere on the board
NEO_PIX1_OUT: LED16.2-DOUT (DO), LED17.4-DIN (DI)


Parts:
AMP: TPA2008D2; PWP-TSSOP24
C3, C4, C49, C53, C54, C57, C59, C60: 0.1uf; C0805
C27, C32, C33, C34: 1uf; C0805
C28: 10uf; C0805
C29: 220 pf; C0805
C48, C50, C58: 2.2uf; C0805
DIN: JUMPER-SMT_2_NC_TRACE_SILK; SMT-JUMPER_2_NC_TRACE_SILK
DOUT: JUMPER-SMT_2_NC_TRACE_SILK; SMT-JUMPER_2_NC_TRACE_SILK
FERRITE1: 600; RESC0805_N
J1, J2, J3, J4, J5, J6, J8, J9, J10, J11: CONN_03; 1X03
MIC1, MIC2, MIC3, MIC4, MIC5: B2B-PH-K
R5: 120k; M0805
R9: 100R; M0805
U$8: SGTL5000; QFN-32-5X5MM
U$9: AP7313-1.8v; SOT-23

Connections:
3.3V: C58.1, C59.1, C60.1, FERRITE1.1, U$9.1 (IN); also elsewhere on the board
5V: AMP.4 (PVDDL1), AMP.9 (PVDDL2), AMP.13 (VDD), AMP.16 (PVDDR1), AMP.21 (PVDDR2), C27.1, C28.1, C33.1, C34.1; also elsewhere on the board
AGND: AMP.12 (AGND), AMP.EXP (AGND), AMP.EXP@1 (AGND), AMP.EXP@2 (AGND), AMP.EXP@3 (AGND), AMP.EXP@4 (AGND), AMP.EXP@5 (AGND), AMP.EXP@6 (AGND), AMP.EXP@7 (AGND), AMP.EXP@8 (AGND), AMP.EXP@9 (AGND), AMP.EXP@10 (AGND), AMP.EXP@11 (AGND), AMP.EXP@12 (AGND), AMP.EXP@13 (AGND), AMP.EXP@14 (AGND), AMP.EXP@15 (AGND), AMP.EXP@16 (AGND), AMP.EXP@17 (AGND), AMP.EXP@18 (AGND), C3.1, C4.1, C29.1, R5.1, U$8.AGND; also elsewhere on the board
AUDIO_LEFT+: AMP.5 (LOUTP), J1.1, J2.1, J3.1, J4.1, J5.1
AUDIO_LEFT-: AMP.8 (LOUTN), J6.1, J8.1, J9.1, J10.1, J11.1
AUDIO_RIGHT+: AMP.20 (ROUTP), J1.3, J2.3, J3.3, J4.3, J5.3
AUDIO_RIGHT-: AMP.17 (ROUTN), J6.3, J8.3, J9.3, J10.3, J11.3
BCLK: U$8.I2S_SCLK (BCLK); also elsewhere on the board
BYPASS: AMP.22 (BYPASS), C32.1
COSC: AMP.10 (COSC), C29.2
DIN: DIN.1; also elsewhere on the board
DOUT: DOUT.1; also elsewhere on the board
EDITROUTE: C48.1, C49.1, FERRITE1.2, U$8.VDDA, U$8.VDDIO
GND: AMP.6 (PGNDL1), AMP.7 (PGNDL2), AMP.18 (PGNDR1), AMP.19 (PGNDR2), C27.2, C28.2, C32.2, C33.2, C34.2, C48.2, C49.2, C50.2, C57.2, C58.2, C59.2, C60.2, U$8.CTRL_ADR0_CS (ADDR), U$8.CTRL_MODE (MODE), U$8.GND1, U$8.GND2, U$8.GND3, U$9.3 (GND); also elsewhere on the board
LINN: AMP.1 (LINN), C3.2
LOUT_L: AMP.2 (LINP), C53.2
LOUT_R: AMP.23 (RINP), C54.2
LRCLK: U$8.I2S_LRCLK (LRCLK); also elsewhere on the board
MCLK: R9.1; also elsewhere on the board
unnamed: J1.2, MIC1.1
unnamed: J2.2, MIC2.1
unnamed: J3.2, MIC3.1
unnamed: J4.2, MIC4.1
unnamed: J5.2, MIC5.1
unnamed: J6.2, MIC1.2
unnamed: C53.1, U$8.LINEOUT_R (LINEOUTR)
unnamed: C54.1, U$8.LINEOUT_L (LINEOUTL)
unnamed: J8.2, MIC2.2
unnamed: C57.1, U$8.VAG
unnamed: DIN.2, U$8.I2S_DIN (RX)
unnamed: DOUT.2, U$8.I2S_DOUT (TX)
unnamed: R9.2, U$8.SYS_MCLK (MCLK)
unnamed: C50.1, U$8.VDDD, U$9.2 (OUT)
unnamed: J9.2, MIC3.2
unnamed: J10.2, MIC4.2
unnamed: J11.2, MIC5.2
RINN: AMP.24 (RINN), C4.2
ROSC: AMP.11 (ROSC), R5.2
SCL: U$8.CTRL_CLK (SCL); also elsewhere on the board
SDA: U$8.CTRL_DATA (SDA); also elsewhere on the board
TPA_SHDN: AMP.3 (SHDN); also elsewhere on the board
VOL: AMP.14 (VOL); also elsewhere on the board



Board: 2 copper layers, 90.0 x 90.0 mm, 119 parts (40 on the bottom side), 88 nets.

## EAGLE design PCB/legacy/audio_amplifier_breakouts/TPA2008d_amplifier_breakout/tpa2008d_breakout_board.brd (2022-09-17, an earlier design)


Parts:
100K1: 3362_BOURNS_TRIMPOT
C11, C13, C20, C21: 0.1uf; C0805
C15, C22, C23, C24: 1uf; C0805
C16: 10uf; C0805
C19: 0.22uF; C0805
C25, C26, C27, C28: 1nF; C0805
L5, L6, L7, L8: 600Ohm@100MHz; RC-MASTER-SMD_L1206MP
P3, P4: B2B-PH-K
R3: 120k; M0805
R4: 33K; M0805
U$2: TPA2008D2; PWP-TSSOP24
U$3: AUDIO_AMPLIFIER_BREAKOUT

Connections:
5V: C15.1, C16.1, C23.1, C24.1, R4.2, U$2.4 (PVDDL1), U$2.9 (PVDDL2), U$2.13 (VDD), U$2.16 (PVDDR1), U$2.21 (PVDDR2), U$3.5V
AGND: 100K1.P$3, C19.1, R3.1, U$2.12 (AGND), U$2.EXP (AGND), U$2.EXP@1 (AGND), U$2.EXP@2 (AGND), U$2.EXP@3 (AGND), U$2.EXP@4 (AGND), U$2.EXP@5 (AGND), U$2.EXP@6 (AGND), U$2.EXP@7 (AGND), U$2.EXP@8 (AGND), U$2.EXP@9 (AGND), U$2.EXP@10 (AGND), U$2.EXP@11 (AGND), U$2.EXP@12 (AGND), U$2.EXP@13 (AGND), U$2.EXP@14 (AGND), U$2.EXP@15 (AGND), U$2.EXP@16 (AGND), U$2.EXP@17 (AGND), U$2.EXP@18 (AGND)
AUDIO_LEFT+: C26.1, L6.1, U$2.5 (LOUTP)
AUDIO_LEFT-: C25.1, L5.1, U$2.8 (LOUTN)
AUDIO_RIGHT+: C28.1, L8.1, U$2.20 (ROUTP)
AUDIO_RIGHT-: C27.1, L7.1, U$2.17 (ROUTN)
BYPASS: C22.1, U$2.22 (BYPASS)
COSC: C19.2, U$2.10 (COSC)
FAULT: U$3.FAULT
GND: C15.2, C16.2, C22.2, C23.2, C24.2, C25.2, C26.2, C27.2, C28.2, U$2.6 (PGNDL1), U$2.7 (PGNDL2), U$2.18 (PGNDR1), U$2.19 (PGNDR2), U$3.GND
LIN+: C13.2, U$3.LIN+
LIN-: C11.2, U$3.LIN-
LINN-1: C11.1, U$2.1 (LINN)
LINP-1: C13.1, U$2.2 (LINP)
LOUT+: L6.2, P3.2, U$3.LOUT+
LOUT-: L5.2, P3.1, U$3.LOUT-
unnamed: 100K1.P$2, R4.1
RIN+: C21.2, U$3.RIN+
RIN-: C20.2, U$3.RIN-
RINN: C20.1, U$2.24 (RINN)
RINP: C21.1, U$2.23 (RINP)
ROSC: R3.2, U$2.11 (ROSC)
ROUT+: L8.2, P4.2, U$3.ROUT+
ROUT-: L7.2, P4.1, U$3.ROUT-
SHDN: U$2.3 (SHDN), U$3.SD
VOL: 100K1.P$1, U$2.14 (VOL)



Board: 2 copper layers, 20.4 x 28.0 mm, 25 parts (11 on the bottom side), 25 nets.

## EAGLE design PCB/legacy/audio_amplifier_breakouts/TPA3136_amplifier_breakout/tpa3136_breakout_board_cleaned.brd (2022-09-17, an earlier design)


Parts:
AUTO_SHUTDOWN1, AUTO_SHUTDOWN4: CONN_02; 1X02
C1, C2, C3, C4, C5, C6, C8, C11, C14, C15, C17, C18, C20, C21, C23, C24, C26, C27, C28: 1uF; CAPC2012X110
C7, C10: 0.1uF; CAPC2012X110
C9, C12: 100uF; CAPC3216X135
C13, C16, C19, C22: 0.33uF; CAPC2012X110
C25: 0.22uF; CAPC2012X110
LIMIT2: 100k; 3362_BOURNS_TRIMPOT
R1, R3: 100k; RESC2012X65
R2, R4, R5, R6, R7, R8, R9, R10, R11: 10k; RESC2012X65
TPA3136D2PWPR2: AUDIO_AMPLIFIER_BREAKOUT
U1: TPA3136D2PWPRALL_CONNECTED; IC_TPS61196PWPRQ1

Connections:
5V: C6.1, C7.1, C8.1, C9.1, C10.1, C11.1, C12.1, R1.1, R3.2, TPA3136D2PWPR2.5V, U1.7 (AVCC), U1.15 (PVCC), U1.16 (PVCC-1), U1.27 (PVCC-2), U1.28 (PVCC-3)
ASDFSDF: AUTO_SHUTDOWN4.1
BSNL: C25.1, U1.22 (BSNL)
BSNR: C26.1, U1.21 (BSNR)
BSPL: C27.1, U1.26 (BSPL)
BSPR: C28.1, U1.17 (BSPR)
EMPTY: U1.5 (EMPTY)
FAULT: AUTO_SHUTDOWN1.2, TPA3136D2PWPR2.FAULT, U1.2 (FAULT)
GND: C1.2, C6.2, C7.2, C8.2, C9.2, C10.2, C11.2, C12.2, C14.2, C17.2, C20.2, C23.2, R2.1, R4.2, R5.2, R6.2, R7.2, R8.2, R9.2, R10.2, R11.2, TPA3136D2PWPR2.GND, U1.8 (GND), U1.19 (GND-1), U1.24 (GND-2), U1.29 (GND-PAD), U1.30 (GND-PAD), U1.31 (GND-PAD), U1.32 (GND-PAD), U1.33 (GND-PAD), U1.34 (GND-PAD), U1.35 (GND-PAD), U1.36 (GND-PAD), U1.37 (GND-PAD), U1.38 (GND-PAD), U1.39 (GND-PAD), U1.40 (GND-PAD), U1.41 (GND-PAD), U1.42 (GND-PAD), U1.43 (GND-PAD), U1.44 (GND-PAD), U1.45 (GND-PAD), U1.46 (GND-PAD), U1.47 (GND-PAD), U1.48 (GND-PAD), U1.49 (GND-PAD), U1.50 (GND-PAD)
LIMIT: LIMIT2.P$1, U1.10 (PLIMIT)
LIN+: C4.1, TPA3136D2PWPR2.LIN+
LIN-: C5.1, TPA3136D2PWPR2.LIN-
LOUT+: C19.1, C20.1, C21.1, C27.2, TPA3136D2PWPR2.LOUT+, U1.25 (OUTPL)
LOUT-: C13.1, C14.1, C15.1, C25.2, TPA3136D2PWPR2.LOUT-, U1.23 (OUTNL)
unnamed: C3.2, U1.11 (RINN)
unnamed: C2.2, U1.12 (RINP)
unnamed: C4.2, U1.3 (LINP)
unnamed: C5.2, U1.4 (LINN)
unnamed: C1.1, LIMIT2.P$2, U1.9 (GVDD)
unnamed: LIMIT2.P$3, R2.2
unnamed: C13.2, R4.1
unnamed: C15.2, R5.1
unnamed: C16.2, R6.1
unnamed: C18.2, R7.1
unnamed: C19.2, R8.1
unnamed: C21.2, R9.1
unnamed: C22.2, R10.1
unnamed: C24.2, R11.1
unnamed: AUTO_SHUTDOWN4.2, R3.1, U1.14 (PBTL)
RINN: C3.1, TPA3136D2PWPR2.RIN-
RINP: C2.1, TPA3136D2PWPR2.RIN+
ROUT+: C22.1, C23.1, C24.1, C28.2, TPA3136D2PWPR2.ROUT+, U1.18 (OUTPR)
ROUT-: C16.1, C17.1, C18.1, C26.2, TPA3136D2PWPR2.ROUT-, U1.20 (OUTNR)
SD: AUTO_SHUTDOWN1.1, R1.2, TPA3136D2PWPR2.SD, U1.1 (SD)



Board: 2 copper layers, 20.3 x 27.9 mm, 44 parts (12 on the bottom side), 32 nets.

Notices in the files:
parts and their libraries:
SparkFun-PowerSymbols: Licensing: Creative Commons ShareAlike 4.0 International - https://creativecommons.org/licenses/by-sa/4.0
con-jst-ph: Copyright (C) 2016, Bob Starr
